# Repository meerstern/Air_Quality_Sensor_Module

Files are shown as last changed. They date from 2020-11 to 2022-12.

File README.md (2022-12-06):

# エアクオリティセンサ基板  
Air_Quality_Sensor_Module

## 概要 
  * ルネサスエレクトロニクス製 [室内空気質（IAQ）センサZMOD4410][1]及び[温湿度センサHS3001][2]を搭載したセンサ基板と専用変換基板です  
  * 専用変換基板を使用することで抵抗値からCO2等に変換する計算アルゴリズムをマイコン側に実装する必要がありません  
  * Arduino等のI2C通信を介して専用変換基板から容易に温湿度、CO2値等の情報を読み出すことが可能です 
  * 変換基板の[SEN]のコネクタにセンサ基板を接続し、[MPU]のコネクタにArduino等のマスタデバイスを接続してください  
  * 計算アルゴリズムはメーカ提供の学習済みニューラルネットワークを使用したファームウェア(20/10/19リリース版)を使用しています  
  * 学習済みニューラルネットワークによって従来よりもより正確にCO2値（eCO2）を推定できます  
  * 専用変換基板のLEDでIAQ(屋内空気質基準IAQ:2以下 青、2-3:青、黄、3-4:黄、4-5:黄、赤、5以上:赤)を確認できます  
  * MPU側のGrove互換コネクタに電源を供給するだけでもIAQレベルLEDで大まかな空気状態を確認することが可能です  
  * 専用変換基板の読み出し方法はサンプルプログラム(Arduino、[USBシリアルI2C変換基板][3]を使用したNode-Red)を参照してください  
  * 専用変換基板から読み出せる値は下記の通りです  
  * 専用変換基板の値は浮動小数点から10倍もしくは100倍した値を16bit符号無データ(温度のみ符号有)に変換しています  
  * センサ基板と専用変換基板、Grove互換ケーブル1本を同梱しています  
  * お手持ちの機器と変換基板を接続するGroveケーブルは同梱されていません  
  * 専用変換基板はGrove互換コネクタを搭載しており、3.3V~5V電源で駆動します  
  * I2C接続の他、Uart9600bpsでセンサデータを受信できます  
  
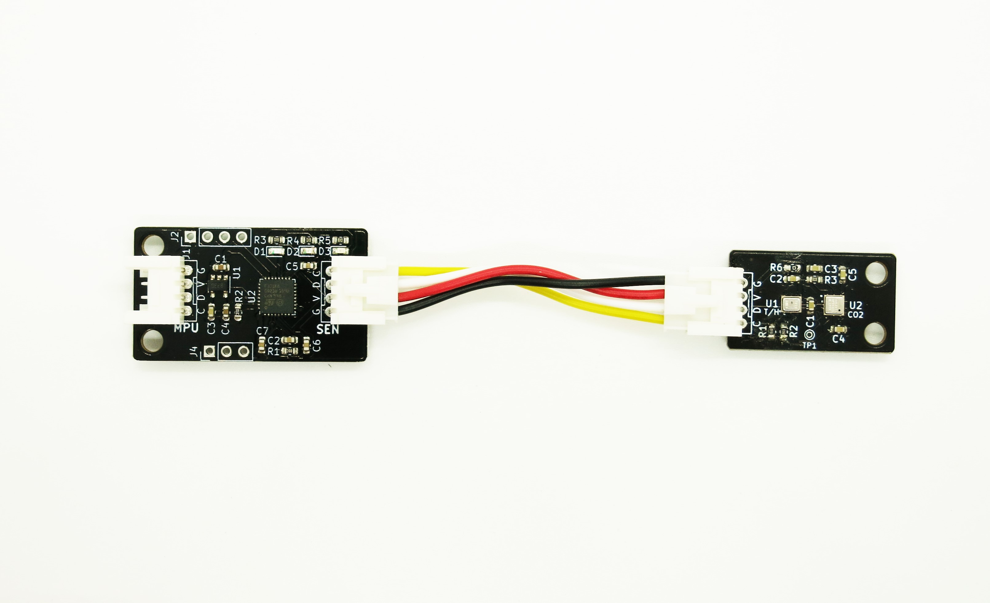
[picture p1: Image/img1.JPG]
  
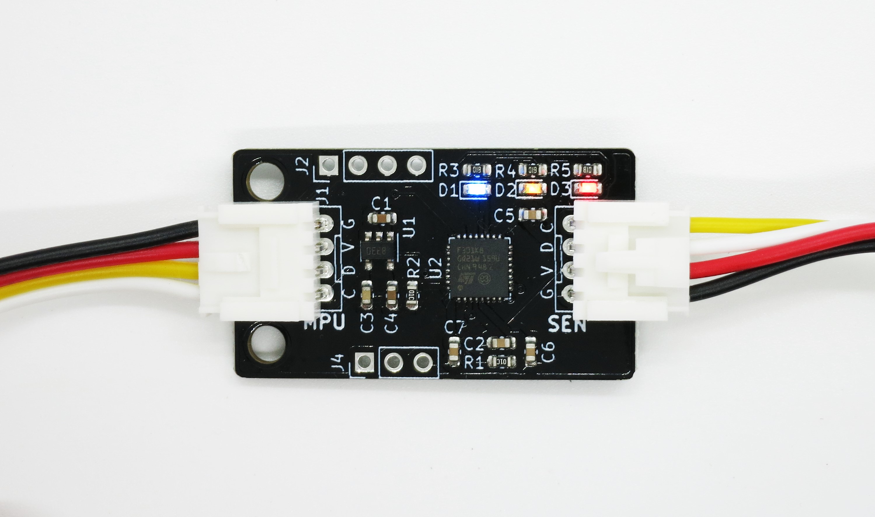
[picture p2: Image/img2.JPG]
  
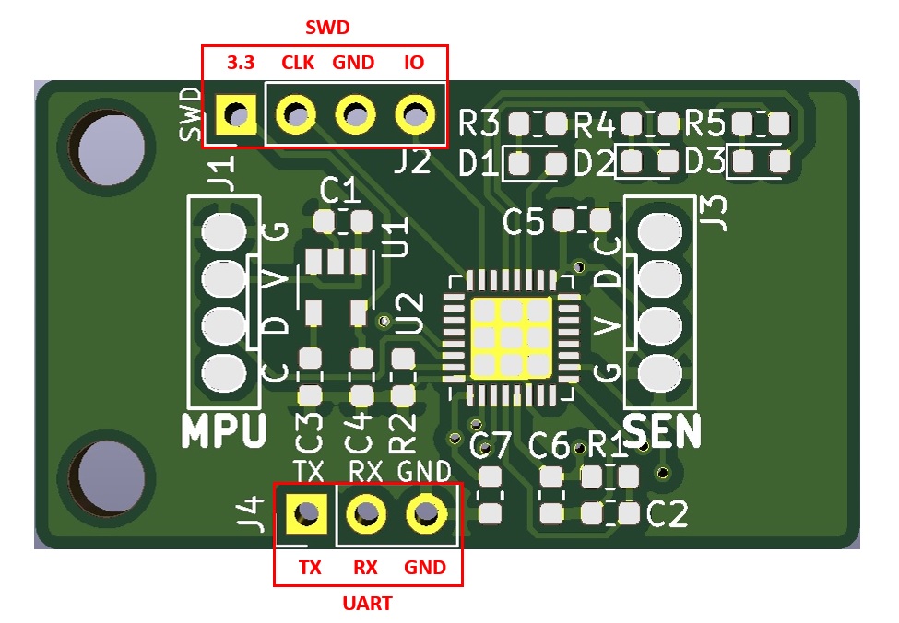
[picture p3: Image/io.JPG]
　
   
  |  項目  |  範囲  |  倍率  |
| ---- | ---- | ---- |
|  温度  |  -40-125℃  |  100倍  |
|  湿度  |  0-100%RH  |  100倍  |
|  CO2  |  400-5000ppm  |  10倍  |
|  IAQ  |  1.0-5.0  |  100倍  |
|  TVOC  |  0.01-10mg/m3  |  100倍  |
|  EtOH  |  0.01-655ppm*1  |  100倍  |
|  LogRcda  |  -  |  100倍  |      
 
 *1 専用変換基板上での制約で最大1000ppm→655ppmとなっています  
    
 ドイツ環境庁（UBA）の屋内空気質（IAQ）基準
 
  |  IAQ  |  レベル  |  LED  |
| ---- | ---- | ---- |
|  <2  |  非常に良い  |  青  |
|  2~3  |  良い  |  青と黄  |
|  3~4  |  中間  |  黄  |
|  4~5  |  悪い  |  黄と赤  |
|  5~  |  非常に悪い | 赤 |

## 注意 
 * 本センサはMOX(Metal Oxide)式のCO2センサのため、空気中の有機物から間接的にCO2に換算します。厳密なCO2計測には向きません  
 * 安定した測定をするために人通りや気流の変化が少ない場所に設置して使用してください  
 * キャリブレーション後にCO2値が安定するまで約0.5~1時間程度要します  
 * IAQは総合的な空気質の指標のため、CO2値が低くても他の有機物が多い場合に高くなります  
 * [SEN]コネクタと[MPU]コネクタの接続間違いに注意してください  
 * 電源投入後、2~3分はキャリブレーションのため、温湿度以外の値は未定で、全LEDが点灯します  
 * 専用変換基板は約2秒周期で各センサの値を取得します(データ更新時にLEDが点滅します)  
 * ZMOD4401はヒータを内蔵するため、電流を確保できる電源を使用してください(最大10mA)  
 * 専用変換基板は5V対応しておりますが、センサ基板は3.3V専用です  
 * ZMOD4410に直接アクセスして使用する場合はルネサスエレクトロニクス社にファームウェアの取得申請が必要です(法人・研究向け)  
 * ルネサスエレクトロニクス社の計算アルゴリズムは*.libもしくは*.aファイルのバイナリ形式で提供されます  
 * 告知なしに仕様を変更する場合があります    

## 参考
 * 第三者機関による[CO2センサ性能評価レポート(PDF,英語のみ)][4]  
 レポートでは他のセンサよりもZMOD4410が実際のCO2濃度に最も近い相関を示すことが報告されています  

## 販売サイト
  * [スイッチサイエンス][5]

[1]: https://www.idt.com/jp/ja/products/sensor-products/gas-sensors/zmod4410-indoor-air-quality-sensor-platform
[2]: https://www.idt.com/us/ja/products/sensor-products/humidity-sensors/hs3001-high-performance-relative-humidity-and-temperature-sensor
[3]: https://github.com/meerstern/USBSerial_I2C_Converter
[4]: https://www.renesas.com/jp/ja/document/rep/ksi-report-algorithm-evaluation-eco2-tracking?language=en
[5]: https://www.switch-science.com/products/6775

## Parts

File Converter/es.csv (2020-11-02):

ID | 参照記号 | パッケージ | 数 | 名称 | Supplier and ref
1 | U2 | QFN-32-1EP_5x5mm_P0.5mm_EP3.45x3.45mm | 1 | STM32F301K8Ux
2 | REF2,REF1 | MountingHole_3.2mm_M3 | 2 | MountingHole_3.2mm_M3
3 | J2 | PinHeader_1x04_P2.54mm_Vertical | 1 | SWD
4 | U1 | SOT-23-5 | 1 | LD3985M33R_SOT23
5 | J3,J1 | GROVE | 2 | Conn_01x04
6 | C4,C1 | C_0603_1608Metric | 2 | 2.2u
7 | C3 | C_0603_1608Metric | 1 | 0.01u
8 | C2,C5,C6,C7 | C_0603_1608Metric | 4 | 0.1u
9 | D1,D2,D3 | D_0603_1608Metric | 3 | LED
10 | J4 | PinHeader_1x03_P2.54mm_Vertical | 1 | Conn_01x03
11 | R1,R2 | R_0603_1608Metric | 2 | 10k
12 | R3,R4,R5 | R_0603_1608Metric | 3 | 1k

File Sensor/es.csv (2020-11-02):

ID | 参照記号 | パッケージ | 数 | 名称 | Supplier and ref
1 | U2 | ZMOD4410 | 1 | ZMOD4410
2 | R6 | R_0603_1608Metric | 1 | 10
3 | R2,R1 | R_0603_1608Metric | 2 | 4.7k
4 | REF2,REF1 | MountingHole_3.2mm_M3 | 2 | MountingHole_3.2mm_M3
5 | U1 | HS300X | 1 | HS300X
6 | TP1 | TestPoint_THTPad_D1.0mm_Drill0.5mm | 1 | TestPoint
7 | R3 | R_0603_1608Metric | 1 | 200k
8 | J1 | GROVE | 1 | Conn_01x04
9 | C5,C4,C3,C2,C1 | C_0603_1608Metric | 5 | 0.1u

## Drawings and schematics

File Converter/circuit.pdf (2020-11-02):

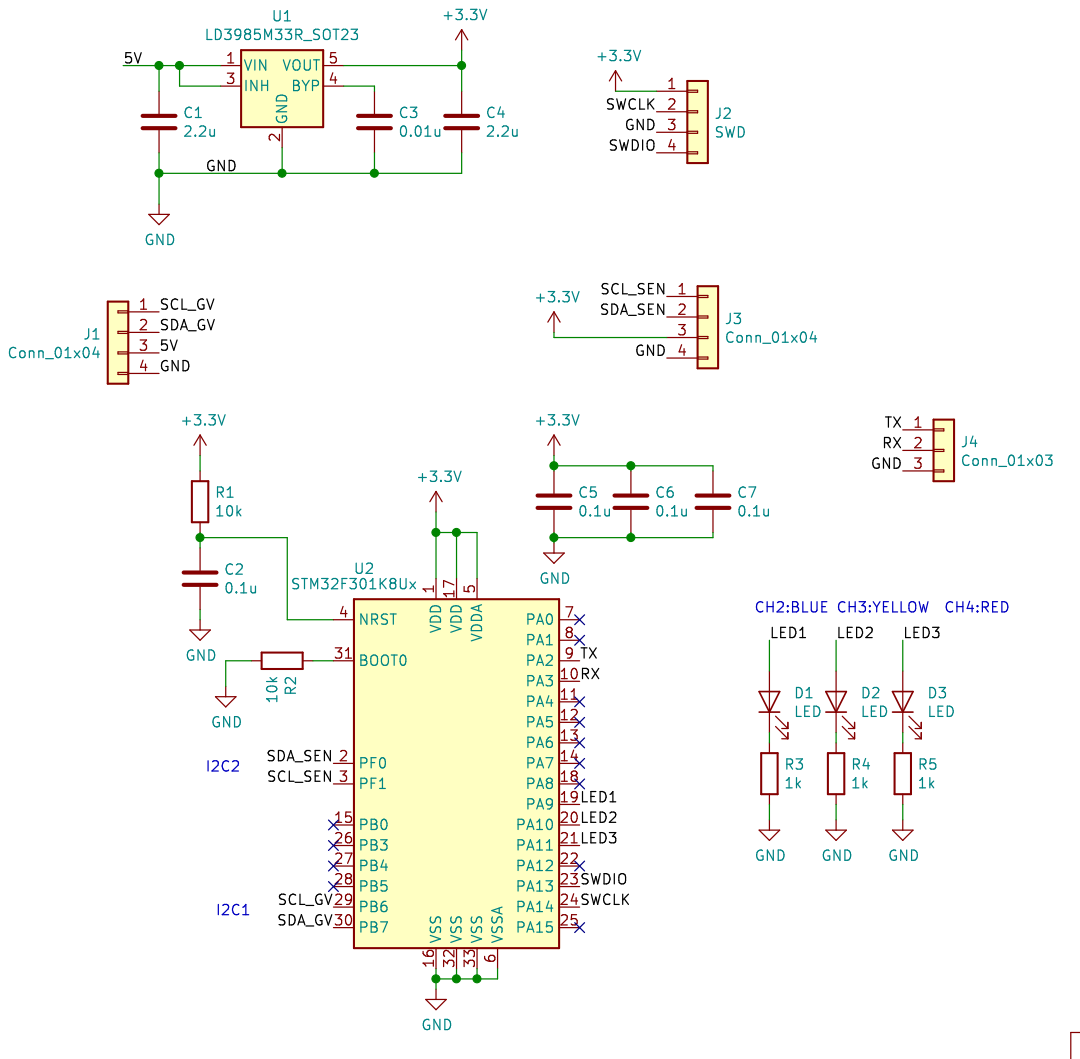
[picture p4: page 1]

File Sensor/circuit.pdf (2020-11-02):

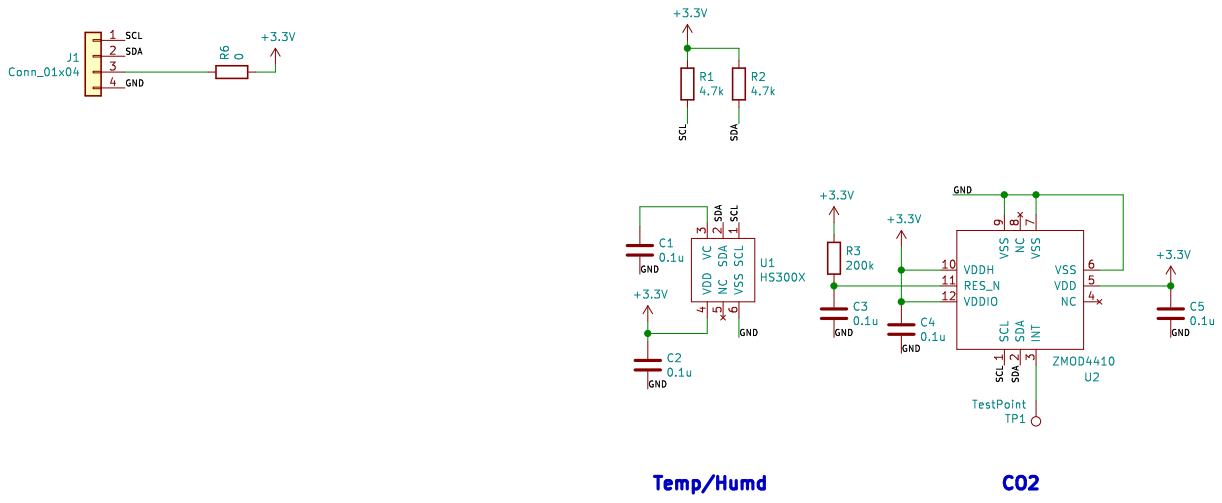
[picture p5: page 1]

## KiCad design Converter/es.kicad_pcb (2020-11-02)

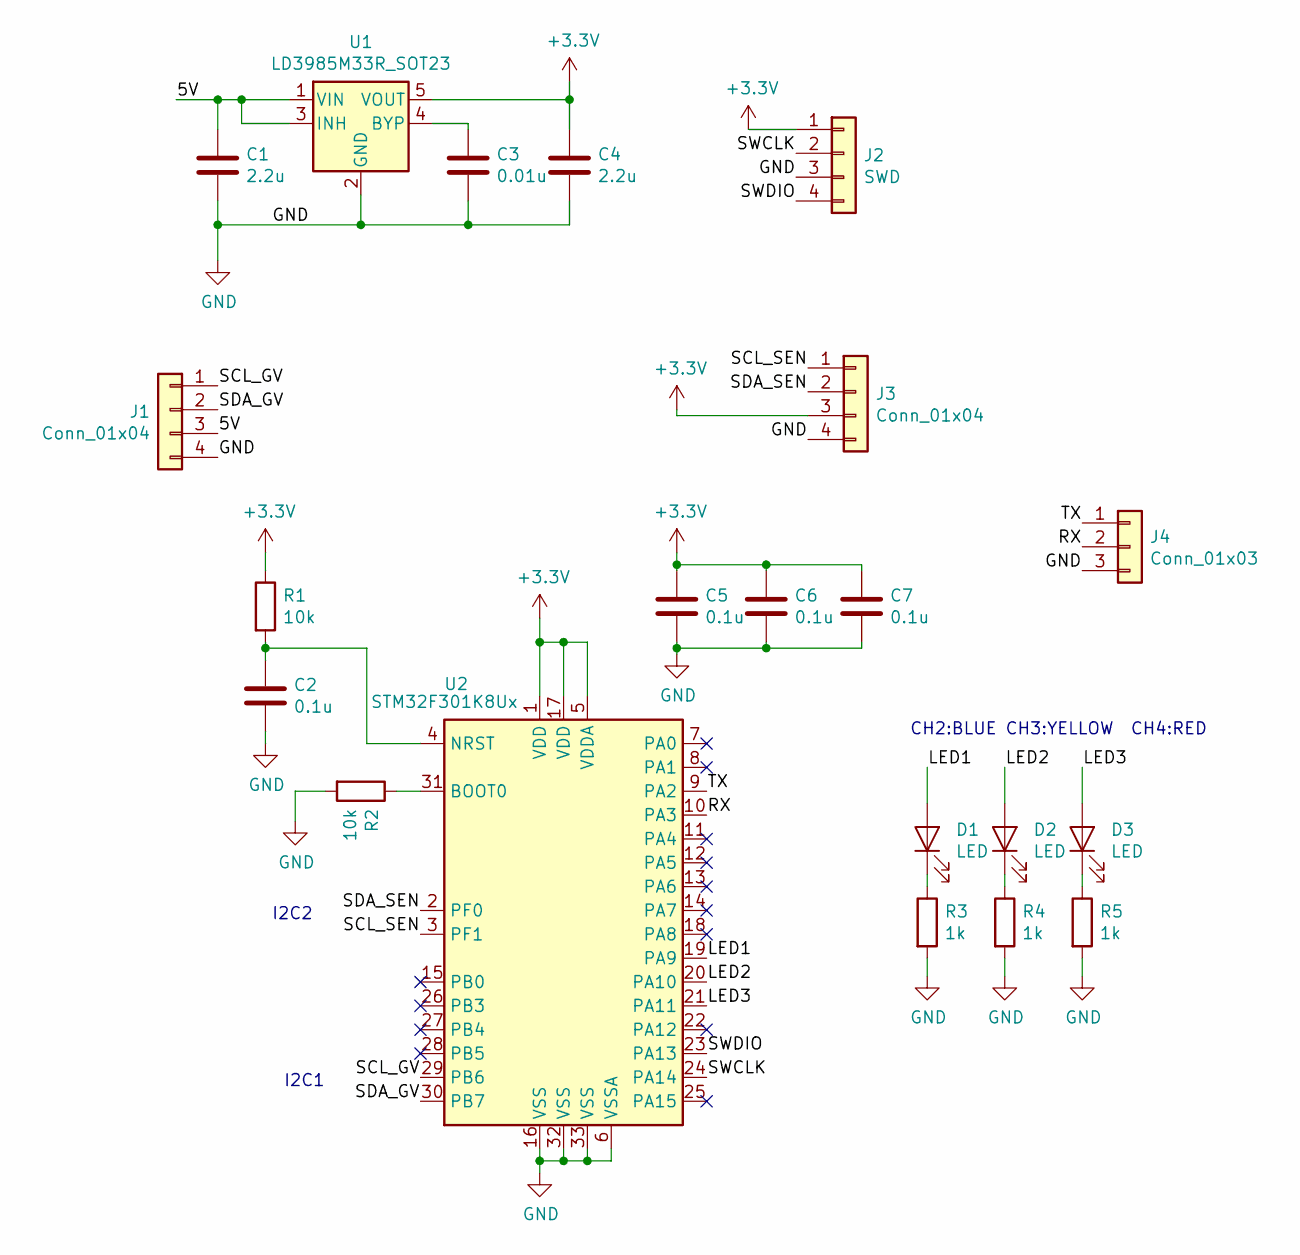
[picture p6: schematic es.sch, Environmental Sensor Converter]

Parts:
C1, C4: 2.2u; C_0603_1608Metric
C2, C5, C6, C7: 0.1u; C_0603_1608Metric
C3: 0.01u; C_0603_1608Metric
D1, D2, D3: LED; D_0603_1608Metric
J1, J3: Conn_01x04; GROVE
J2: SWD; PinHeader_1x04_P2.54mm_Vertical
J4: Conn_01x03; PinHeader_1x03_P2.54mm_Vertical
R1, R2: 10k; R_0603_1608Metric
R3, R4, R5: 1k; R_0603_1608Metric
U1: LD3985M33R_SOT23; SOT-23-5
U2: STM32F301K8Ux; QFN-32-1EP_5x5mm_P0.5mm_EP3.45x3.45mm

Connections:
+3V3: C4.1, C5.1, C6.1, C7.1, J2.1, J3.3, R1.1, U1.5 (VOUT), U2.1 (VDD), U2.5 (VDDA), U2.17 (VDD)
/5V: C1.1, J1.3, U1.1 (VIN), U1.3 (INH)
/LED1: D1.2 (A), U2.19 (PA9)
/LED2: D2.2 (A), U2.20 (PA10)
/LED3: D3.2 (A), U2.21 (PA11)
/RX: J4.2, U2.10 (PA3)
/SCL_GV: J1.1, U2.29 (PB6)
/SCL_SEN: J3.1, U2.3 (PF1)
/SDA_GV: J1.2, U2.30 (PB7)
/SDA_SEN: J3.2, U2.2 (PF0)
/SWCLK: J2.2, U2.24 (PA14)
/SWDIO: J2.4, U2.23 (PA13)
/TX: J4.1, U2.9 (PA2)
GND: C1.2, C2.2, C3.2, C4.2, C5.2, C6.2, C7.2, J1.4, J2.3, J3.4, J4.3, R2.2, R3.2, R4.2, R5.2, U1.2 (GND), U2.6 (VSSA), U2.16 (VSS), U2.32 (VSS), U2.33 (VSS)
unnamed: C2.1, R1.2, U2.4 (NRST)
unnamed: C3.1, U1.4 (BYP)
unnamed: D1.1 (K), R3.1
unnamed: D2.1 (K), R4.1
unnamed: D3.1 (K), R5.1
unnamed: R2.1, U2.31 (BOOT0)

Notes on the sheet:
I2C2
I2C1
CH2:BLUE
CH3:YELLOW
CH4:RED

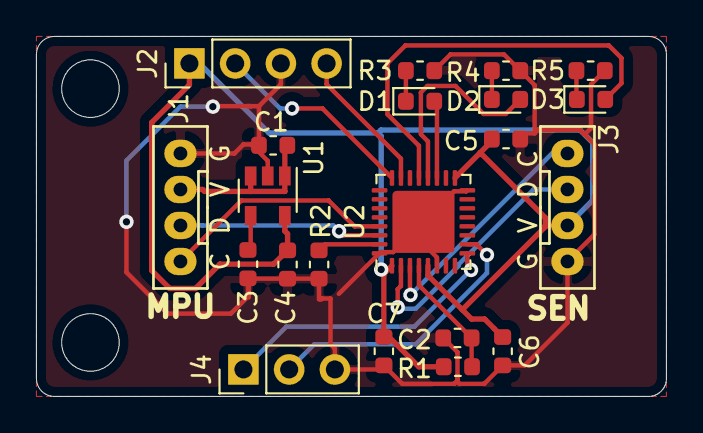
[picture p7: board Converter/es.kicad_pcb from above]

Board: 2 copper layers, 35.0 x 20.0 mm, 23 parts (0 on the bottom side), 20 nets.

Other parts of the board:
REF1, REF2: MountingHole_3.2mm_M3

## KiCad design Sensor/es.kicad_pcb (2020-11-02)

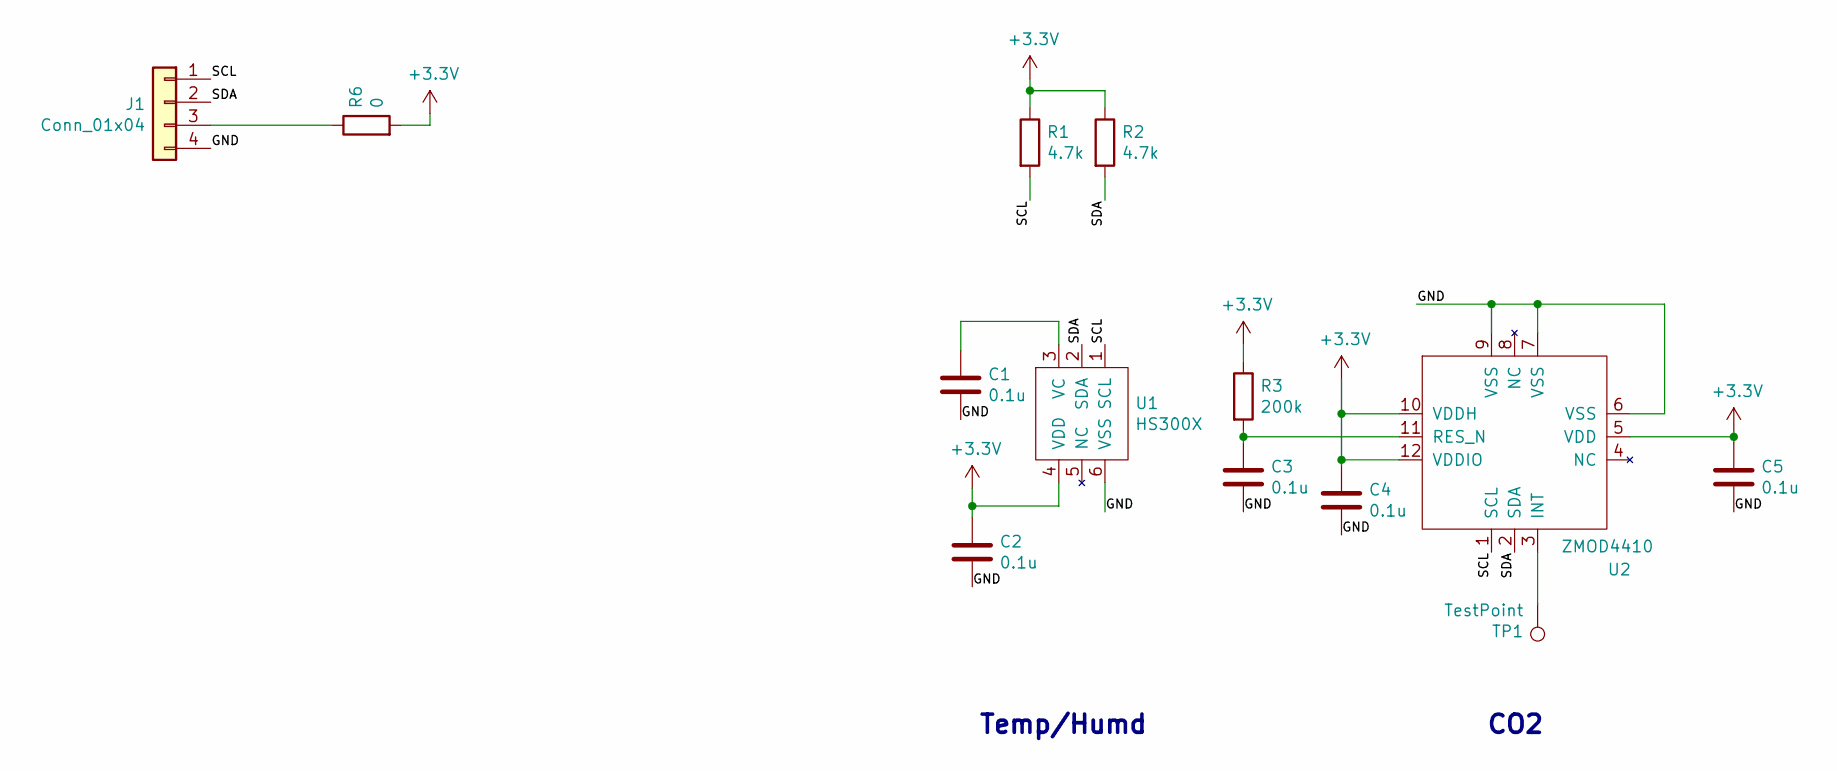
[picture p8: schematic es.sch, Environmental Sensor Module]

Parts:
C1, C2, C3, C4, C5: 0.1u; C_0603_1608Metric
J1: Conn_01x04; GROVE
R1, R2: 4.7k; R_0603_1608Metric
R3: 200k; R_0603_1608Metric
R6: 0; R_0603_1608Metric
TP1: TestPoint; TestPoint_THTPad_D1.0mm_Drill0.5mm
U1: HS300X
U2: ZMOD4410

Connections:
+3V3: C2.1, C4.1, C5.1, R1.1, R2.1, R3.1, R6.2, U1.4 (VDD), U2.5 (VDD), U2.10 (VDDH), U2.12 (VDDIO)
/GND: C1.2, C2.2, C3.2, C4.2, C5.2, J1.4, U1.6 (VSS), U2.6 (VSS), U2.7 (VSS), U2.9 (VSS)
/SCL: J1.1, R1.2, U1.1 (SCL), U2.1 (SCL)
/SDA: J1.2, R2.2, U1.2 (SDA), U2.2 (SDA)
unnamed: C1.1, U1.3 (VC)
unnamed: C3.1, R3.2, U2.11 (RES_N)
unnamed: J1.3, R6.1
unnamed: TP1.1, U2.3 (INT)

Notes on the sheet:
CO2
Temp/Humd

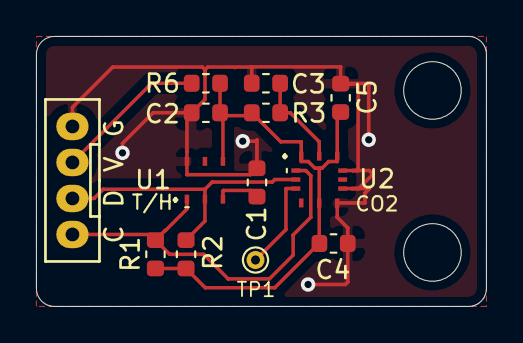
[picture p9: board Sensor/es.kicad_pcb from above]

Board: 2 copper layers, 25.0 x 15.0 mm, 15 parts (0 on the bottom side), 8 nets.

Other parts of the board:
REF1, REF2: MountingHole_3.2mm_M3

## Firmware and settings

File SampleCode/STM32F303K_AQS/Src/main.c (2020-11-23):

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

/* Includes ------------------------------------------------------------------*/
#include "main.h"

/* USER CODE BEGIN Includes */
#include <stdio.h>
/* USER CODE END Includes */

/* USER CODE BEGIN PTD */
#define AQS_ADDRESS   (0x32<<1)
#define AQS_DATA_LEN  16
#define AQS_ID        0x43
/* USER CODE END PTD */

I2C_HandleTypeDef hi2c1;

UART_HandleTypeDef huart2;

void SystemClock_Config(void);
static void MX_GPIO_Init(void);
static void MX_I2C1_Init(void);
static void MX_USART2_UART_Init(void);
/* USER CODE BEGIN 0 */
int _write (int fd, char *ptr, int len)
{
  HAL_UART_Transmit(&huart2, (uint8_t*)ptr, len, 1000);
  return len;
}
/* USER CODE END 0 */

/**
  * @brief  The application entry point.
  * @retval int
  */
int main(void)
{
  /* MCU Configuration--------------------------------------------------------*/

  /* Reset of all peripherals, Initializes the Flash interface and the Systick. */
  HAL_Init();

  /* Configure the system clock */
  SystemClock_Config();

  /* Initialize all configured peripherals */
  MX_GPIO_Init();
  MX_I2C1_Init();
  MX_USART2_UART_Init();
  /* USER CODE BEGIN 2 */
  //I2C:SCL,SDA::PB6,PB7::D5,D4
  uint8_t rdata[AQS_DATA_LEN];
  int16_t int_temp,int_humd,int_eth,int_tvoc,int_eco2,int_iaq,int_rcda;
  float temp,humd,eth,tvoc,eco2,iaq,rcda;


  printf("Init OK\n\r");

  /* USER CODE END 2 */

  /* Infinite loop */
  /* USER CODE BEGIN WHILE */
  while (1)
  {
    /* USER CODE END WHILE */

    /* USER CODE BEGIN 3 */

	  HAL_I2C_Mem_Read(&hi2c1,AQS_ADDRESS,0,I2C_MEMADD_SIZE_8BIT,rdata,16,0xFFFF);

	  if(rdata[0]==AQS_ID)  printf("Sensor is Found! ");
	  else                 	printf("Sensor is Not Found! ");

	  if(rdata[1]==1)       printf("Sensor is Ready! \n\r");
	  else                  printf("Sensor is Not Ready! \n\r");

	  if(rdata[0]==AQS_ID)
	  {
		  int_temp = ((rdata[2]&0xFF)<<8) +(rdata[3]&0xFF);
		  int_humd = ((rdata[4]&0xFF)<<8) +(rdata[5]&0xFF);
		  int_eth  = ((rdata[6]&0xFF)<<8) +(rdata[7]&0xFF);
		  int_tvoc = ((rdata[8]&0xFF)<<8) +(rdata[9]&0xFF);
		  int_eco2 = ((rdata[10]&0xFF)<<8) +(rdata[11]&0xFF);
		  int_iaq  = ((rdata[12]&0xFF)<<8) +(rdata[13]&0xFF);
		  int_rcda = ((rdata[14]&0xFF)<<8) +(rdata[15]&0xFF);

		  temp = int_temp/100.0;
		  humd = int_humd/100.0;
		  eth  = int_eth/100.0;
		  tvoc = int_tvoc/100.0;
		  eco2 = int_eco2/10.0;
		  iaq = int_iaq/100.0;
		  rcda = int_rcda/100.0;

		  printf("TMP:%1.1f 'C, HMD:%1.1f %%, eCO2:%1.1f ppm, IAQ:%1.1f, Etoh:%1.1f ppm, TVOC:%1.1f mg/m3, logRcda:%1.1f ohm \n\r",
					 temp, humd, eco2, iaq, eth, tvoc, rcda);
	  }



	  HAL_Delay(2000);


  }
  /* USER CODE END 3 */
}

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


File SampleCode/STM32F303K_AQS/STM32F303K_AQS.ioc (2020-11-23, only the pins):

Mcu.UserName=STM32F303K8Tx
PA13.GPIO_Label=SWDIO
PA13.Signal=SYS_JTMS-SWDIO
PA14.GPIO_Label=SWCLK
PA14.Signal=SYS_JTCK-SWCLK
PA15.GPIO_Label=VCP_RX
PA15.Signal=USART2_RX
PA2.GPIO_Label=VCP_TX
PA2.Signal=USART2_TX
PB6.Signal=I2C1_SCL
PB7.Signal=I2C1_SDA

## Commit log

2020-11-02 add pcb files
    [es-B_Cu.gbl, es-B_Mask.gbs, es-B_Paste.gbp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]
2020-11-12 Add Sample Code
2020-11-23 Add sample codes for STM32F303K8 Nucleo board

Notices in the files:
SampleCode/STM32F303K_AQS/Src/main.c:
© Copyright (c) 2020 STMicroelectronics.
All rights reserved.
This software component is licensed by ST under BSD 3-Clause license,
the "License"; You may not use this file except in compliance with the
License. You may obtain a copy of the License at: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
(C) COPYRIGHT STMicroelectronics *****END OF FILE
